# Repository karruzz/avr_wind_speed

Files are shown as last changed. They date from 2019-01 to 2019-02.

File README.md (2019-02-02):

# About

Wind speed measuring

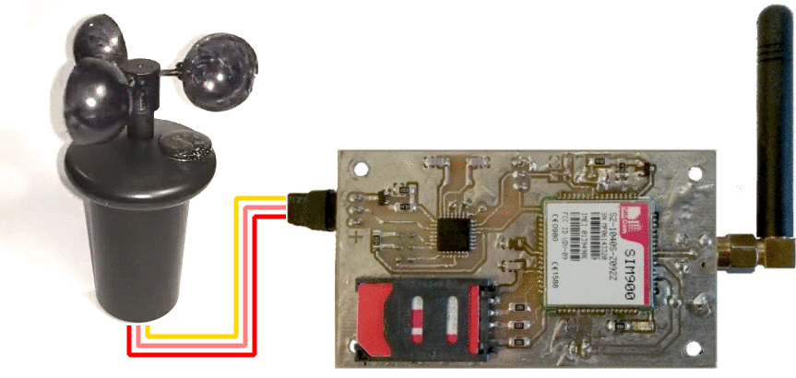
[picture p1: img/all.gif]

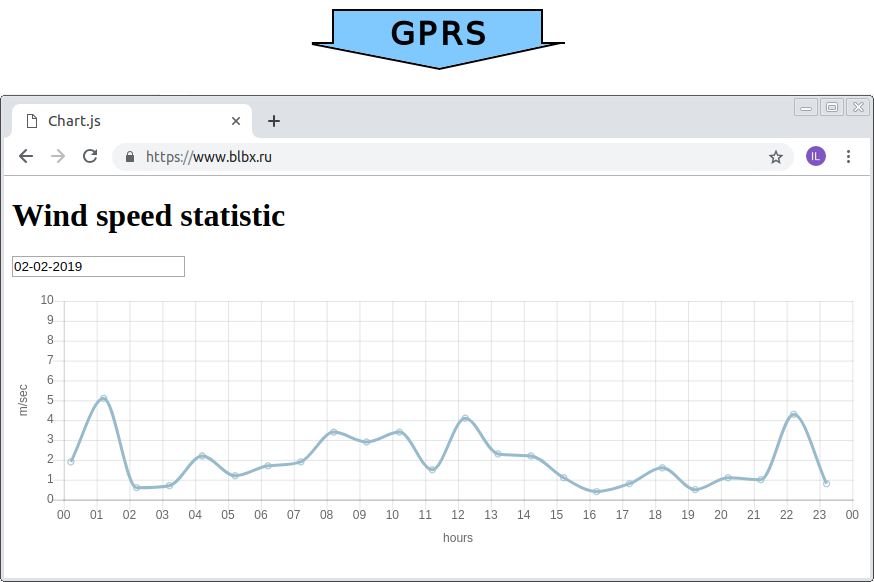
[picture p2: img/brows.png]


# Board schematic

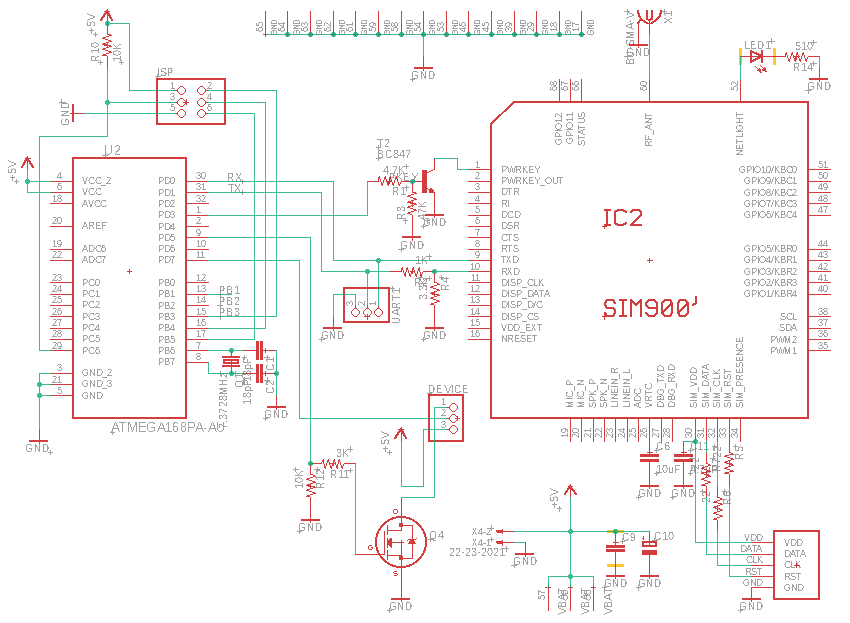
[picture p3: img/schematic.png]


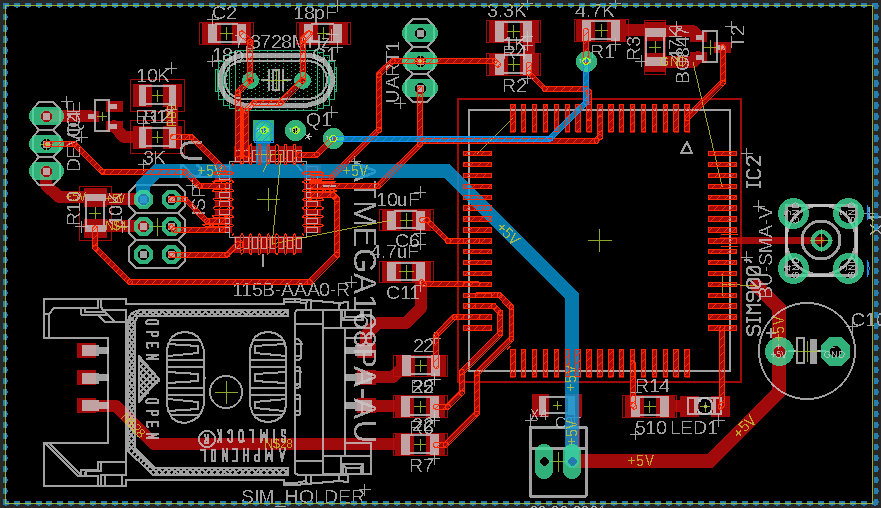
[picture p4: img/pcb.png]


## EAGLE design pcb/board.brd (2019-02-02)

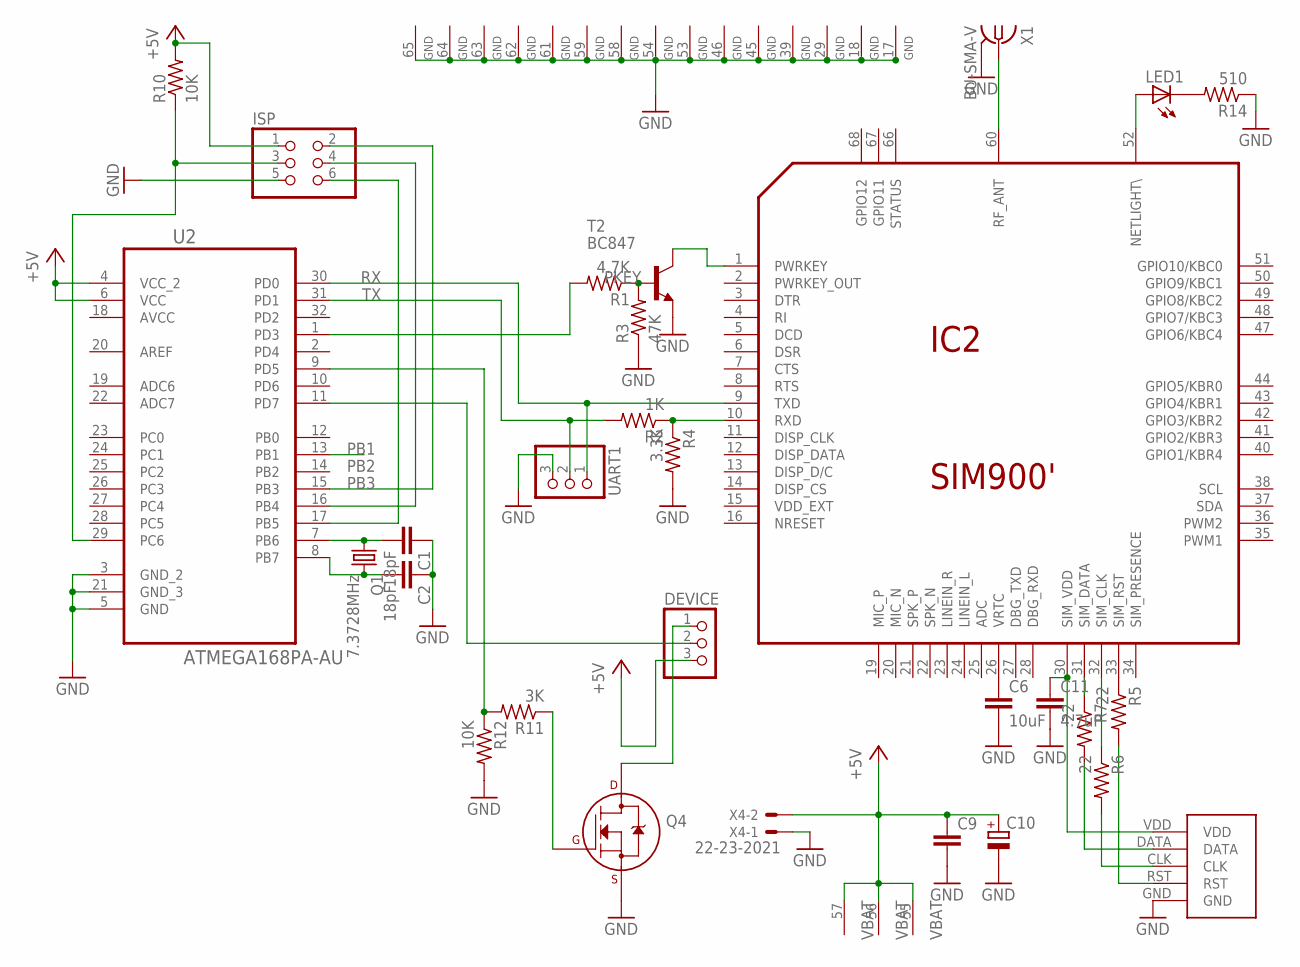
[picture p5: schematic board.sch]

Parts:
C1, C2: 18pF; C1206
C6: 10uF; C1206
C9: C-EUC1206K; C1206K
C10: CPOL-EUE5-8.5; E5-8,5
C11: 4.7uF; C1206
DEVICE: PINHD-1X3; 1X03
IC2: SIM900'; SIM900_NARROW
ISP: PINHD-2X3; 2X03
LED1: LED_E; LED_1206
Q1: 7.3728MHz; HC49U-V
Q4: 2N700_SOT23_1; SOT23
R1: 4.7K; R1206
R2: 1K; R1206
R3: 47K; R1206
R4: 3.3K; R1206
R5, R6, R7: 22; R1206
R10, R12: 10K; M1206
R11: 3K; M1206
R14: 510; R1206
SIM_HOLDER: 115B-AAA0-R; C707_10M006_512_2
T2: BC847; SOT23
U2: ATMEGA168PA-AU; QFP80P900X900X120-32N
UART1: PINHD-1X3; 1X03
X1: BU-SMA-V
X4: 22-23-2021

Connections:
+5V: C9.1, C10.+, DEVICE.3, IC2.55 (VBAT), IC2.56 (VBAT), IC2.57 (VBAT), ISP.1, R10.2, U2.4 (VCC_2), U2.6 (VCC), X4.2
AVCC: U2.18 (AVCC)
GND: C1.1, C2.1, C6.2, C9.2, C10.-, C11.2, IC2.17 (GND), IC2.18 (GND), IC2.29 (GND), IC2.39 (GND), IC2.45 (GND), IC2.46 (GND), IC2.53 (GND), IC2.54 (GND), IC2.58 (GND), IC2.59 (GND), IC2.61 (GND), IC2.62 (GND), IC2.63 (GND), IC2.64 (GND), IC2.65 (GND), ISP.5, Q4.2 (S), R3.1, R4.2, R12.2, R14.1, SIM_HOLDER.GND, T2.2 (E), U2.3 (GND_2), U2.5 (GND), U2.21 (GND_3), UART1.3, X1.2, X1.3 (2), X1.4 (2), X1.5 (2), X4.1
unnamed: C1.2, Q1.1, U2.7 (PB6)
unnamed: DEVICE.2, U2.11 (PD7)
unnamed: Q4.1 (G), R11.1
unnamed: ISP.3, R10.1, U2.29 (PC6)
unnamed: ISP.4, U2.16 (PB4)
unnamed: ISP.6, U2.17 (PB5)
unnamed: IC2.1 (PWRKEY), T2.3 (C)
unnamed: IC2.10 (RXD), R2.1, R4.1
unnamed: R1.1, R3.2, T2.1 (B)
unnamed: C2.2, Q1.2, U2.8 (PB7)
unnamed: IC2.52 (NETLIGHT\), LED1.A
unnamed: LED1.C, R14.2
unnamed: R5.2, SIM_HOLDER.RST
unnamed: C11.1, IC2.30 (SIM_VDD), SIM_HOLDER.VDD
unnamed: C6.1, IC2.26 (VRTC)
unnamed: IC2.31 (SIM_DATA), R7.1
unnamed: IC2.32 (SIM_CLK), R6.1
unnamed: IC2.33 (SIM_RST), R5.1
unnamed: R7.2, SIM_HOLDER.DATA
unnamed: IC2.60 (RF_ANT), X1.1
unnamed: DEVICE.1, Q4.3 (D)
unnamed: R6.2, SIM_HOLDER.CLK
PB1: U2.13 (PB1)
PB2: R11.2, R12.1, U2.9 (PD5)
PB3: ISP.2, U2.15 (PB3)
PKEY: R1.2, U2.1 (PD3)
RX: IC2.9 (TXD), U2.30 (PD0), UART1.1
TX: R2.2, U2.31 (PD1), UART1.2

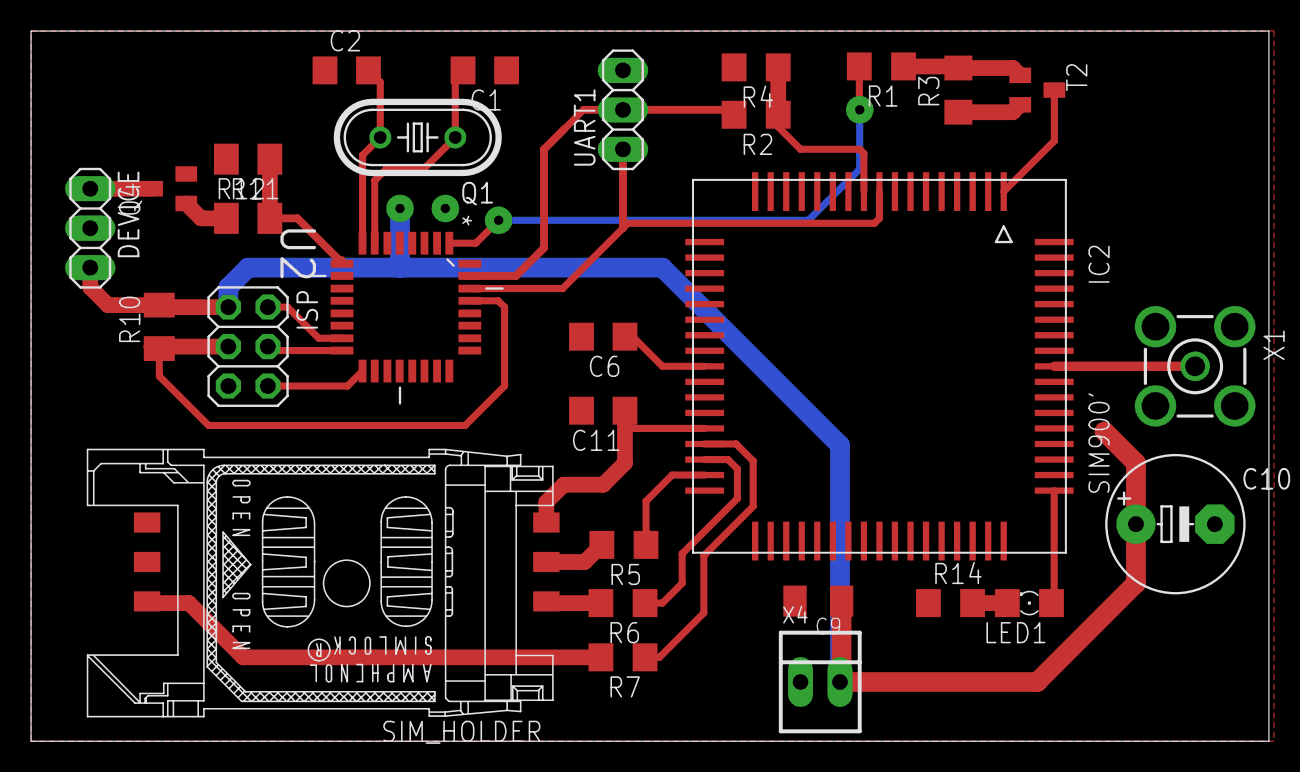
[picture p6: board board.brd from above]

Board: 2 copper layers, 79.7 x 45.7 mm, 29 parts (0 on the bottom side), 29 nets.

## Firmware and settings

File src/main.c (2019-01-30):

/*
 * Gprs.c
 *
 * Created: 20.09.2014 18:18:42
 *  Author: karruzz
 * License: GNU GPL 3
 */

#include <stdio.h>
#include <avr/wdt.h>
#include <util/delay.h>

#include "uart.h"
#include "sim_900.h"
#include "adc.h"

// #define F_CPU 3686400UL  // in cmake
#define BAUD 19200
#define MYUBRR F_CPU/16/BAUD-1
#define SPEED_MEASURMENTS 15
#define FACTORS 3

const int WIND_MEASURE_S = 128; // 1 << 7
const int SIM_WAIT_CONNECTION = 8000;

FILE uart_stream = FDEV_SETUP_STREAM(uart_putc, uart_getc, _FDEV_SETUP_RW);

uint16_t speeds[SPEED_MEASURMENTS];

float K[FACTORS] = { -0.00866, -0.00583, -0.003 };
int16_t x0[FACTORS] = { 1200, 2400, 10000 };
int16_t B[FACTORS] = { 33, 26, 4 };

inline
unsigned int to_speed(unsigned int period)
{
	for (int i = 0; i < FACTORS; i++)
		if (period < x0[i])
			// always positive linear model
			return (uint16_t) K[i] * (period - x0[i]) + B[i];

	return 0;
}

int main(void)
{
	stdout = stdin = &uart_stream;
	uart_init(MYUBRR);

	wdt_disable();
#ifdef DEBUG
	fprintf(stdout, "debug\n");
#else
	fprintf(stdout, "no debug\n");
#endif

	// test on/off for visual control
	sim900_on();
	_delay_ms(SIM_WAIT_CONNECTION);
	sim900_off();

	while(1) {
		adc_on();
		wdt_enable(WDTO_8S);
		for (int i = 0; i < SPEED_MEASURMENTS; ++i) {
			int ticks = 0;
			uint16_t speeds_sum = 0;
			while (ticks < WIND_MEASURE_S) {
				_delay_ms(995);
				speeds_sum += to_speed(adc_get_strobe_period());
				ticks++;
				wdt_reset();
			}

			speeds[i] = (uint16_t)(speeds_sum >> 7);
		}
		wdt_disable();
		adc_off();

		sim900_on();
		_delay_ms(SIM_WAIT_CONNECTION);
		sim900_send_speeds(speeds, SPEED_MEASURMENTS);
		sim900_off();
	}
}

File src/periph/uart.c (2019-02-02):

/*
 * Uart.c
 *
 * Created: 20.09.2014 18:25:47
 *  Author: karruzz
 * License: GNU GPL 3
 */

#include "uart.h"

FIFO( 64 ) uart_tx_fifo;
FIFO( 64 ) uart_rx_fifo;

void uart_init(uint16_t ubrr)
{
	// baudrate
	UBRR0H = (uint8_t)(ubrr>>8);
	UBRR0L = (uint8_t) ubrr;
	// 8 bit data, 1 stop, no parity
	UCSR0C = _BV(UCSZ01) | _BV(UCSZ00);
	// enable, receive, response, interruption
	UCSR0B = _BV(TXEN0) | _BV(RXEN0) | _BV(RXCIE0);
}

// data received from USART
ISR(USART_RX_vect)
{
	uint8_t rxbyte = UDR0;
	if (!FIFO_IS_FULL(uart_rx_fifo))
		FIFO_PUSH(uart_rx_fifo, rxbyte);
}

// data register accepts new data
ISR(USART_UDRE_vect)
{
	if (FIFO_IS_EMPTY(uart_tx_fifo)) {
		UCSR0B &= ~_BV(UDRIE0); // disable this interruption
	} else {
		char txbyte = FIFO_FRONT(uart_tx_fifo);
		FIFO_POP(uart_tx_fifo);
		UDR0 = txbyte;
	}
}

int uart_putc(char c, FILE *file)
{
	int ret;
	if (c == '\n')
		uart_putc('\r', file);

	cli();
	if( !FIFO_IS_FULL(uart_tx_fifo) ) {
		FIFO_PUSH(uart_tx_fifo, c);
		UCSR0B |= _BV(UDRIE0);
		ret = 0;
	} else {
		ret = -1;
	}
	sei();

	return ret;
}

int uart_getc(FILE* file)
{
	int ret;

	cli();
	if( !FIFO_IS_EMPTY(uart_rx_fifo) ) {
		ret = FIFO_FRONT(uart_rx_fifo);
		FIFO_POP(uart_rx_fifo);
	} else {
		ret = _FDEV_EOF;
	}
	sei();

	return ret;
}

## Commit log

2014-10-01 sim initializing fixed (\r sends uart)
2014-11-03 use invalid pin for sensor supplying
2019-02-02 img, data types
    [board.brd, board.sch]
